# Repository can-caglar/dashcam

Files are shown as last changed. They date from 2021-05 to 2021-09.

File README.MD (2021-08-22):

# DASHCAM PROJECT

This is the development repo for a low-cost, dash-cam hobby project.

**Features:**

1. Small size (34 x 34 x 34 cm)

2. Saves videos to AVI format (motion JPEG).

3. Powered through a USB mini cable.

4. Can connect to WiFi. The idea is to connect it to your phone hotspot, after which the video will be streamed to a local server that the driver can access on their phone's internet browser. This is to help the driver position the camera by seeing what the camera is seing.

5. Small OLED screen and 3 buttons for the UI. OLED will show the device IP address for the video streaming server, and show nearby WiFi access points.

6. Inexpensive looking (due to very small design). Will not encourage thieves!

7. Has a supercapacitor which keeps power active for ~ 1 second after power is cut, this means videos will never be corrupt.

8. SD card slot which overrides oldest videos, so the device will never run out of memory. 

9. It's a cube! The x, y and z dimentions have been distributed equally so it takes up as little space from the driver's perspective as possible.

## Latest update:

**Proven concepts**

- Videos can be saved on an ESP32 using an AVI format.

- Supercapacitor keeps the device on long enough for the video to save after abrupt power down.

- OLED library allows scrolling text, so long messages, i.e. IP address of device can be shown easily. 

**Hardware**

PCB spin 1 has arrived and components have been soldered.

The ESP32 can be programmed and can run a basic "hello world" script without issues.

Full circuit could not be tested because the 0.5 mm pitch FPC connectors proved difficult to solder without a hot air gun.

More details can be found in [Project_planning.xlsx](https://github.com/jhancharler/dashcam/blob/master/project_plan/Project_planning.xlsx "Project_planning.xlsx").

## Images:

**Top-side images:**
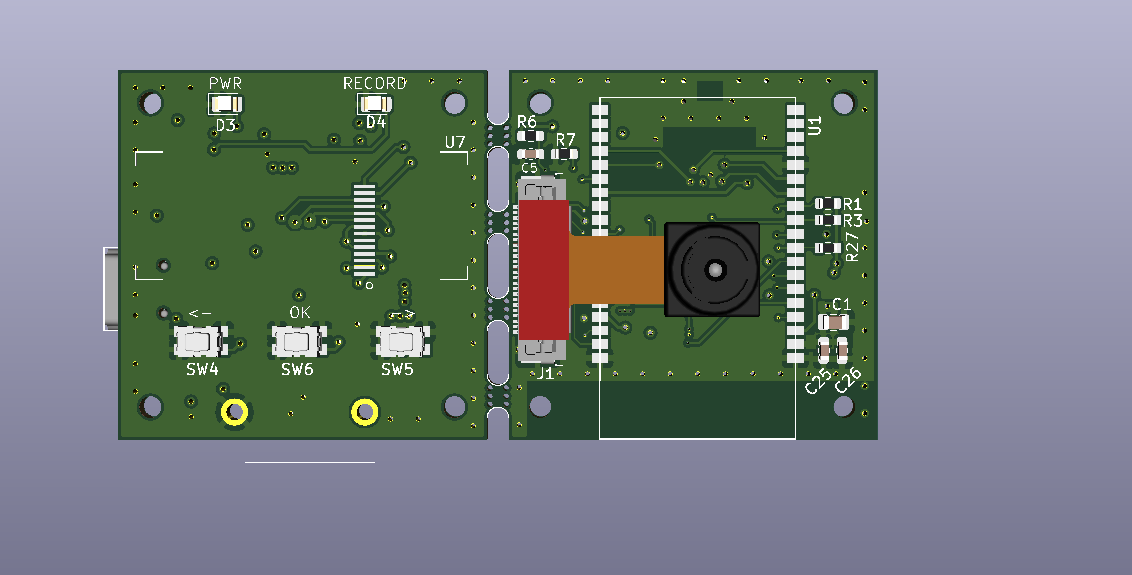
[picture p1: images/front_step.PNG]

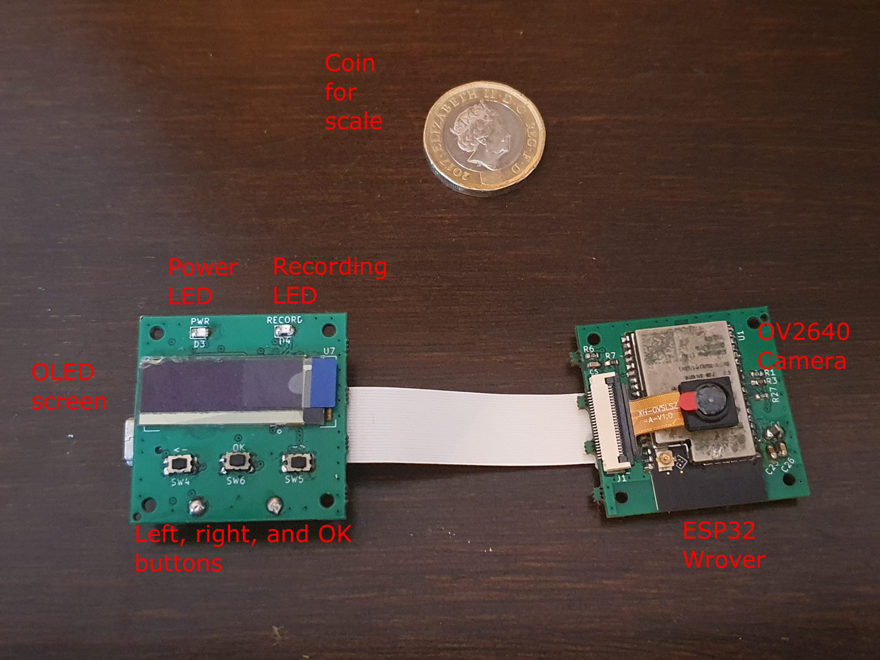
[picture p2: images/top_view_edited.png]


**Back images:**
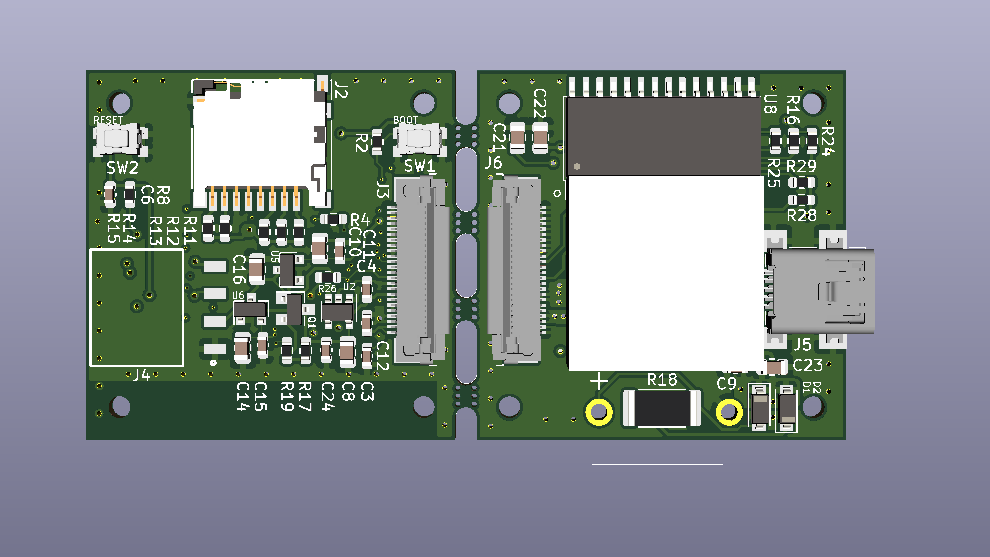
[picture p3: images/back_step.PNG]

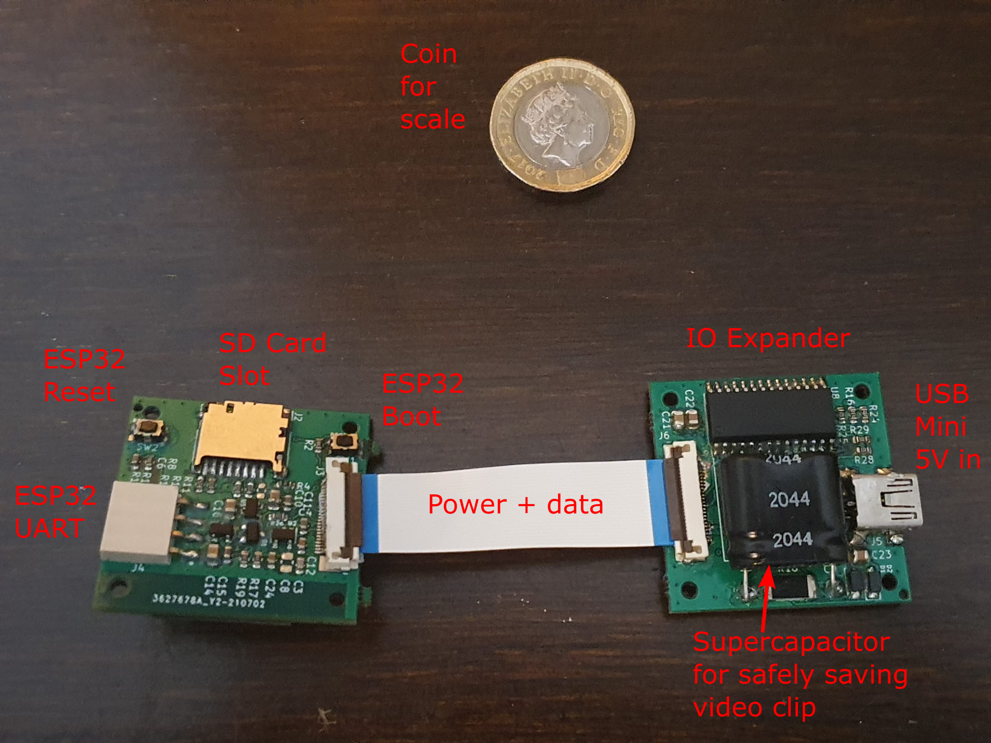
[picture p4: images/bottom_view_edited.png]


**Upright images:**
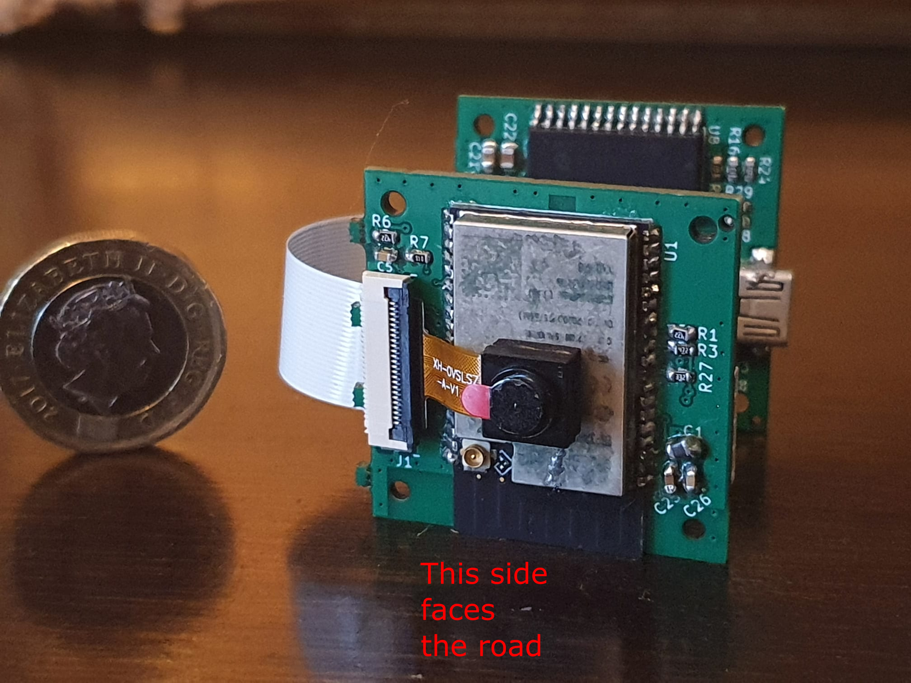
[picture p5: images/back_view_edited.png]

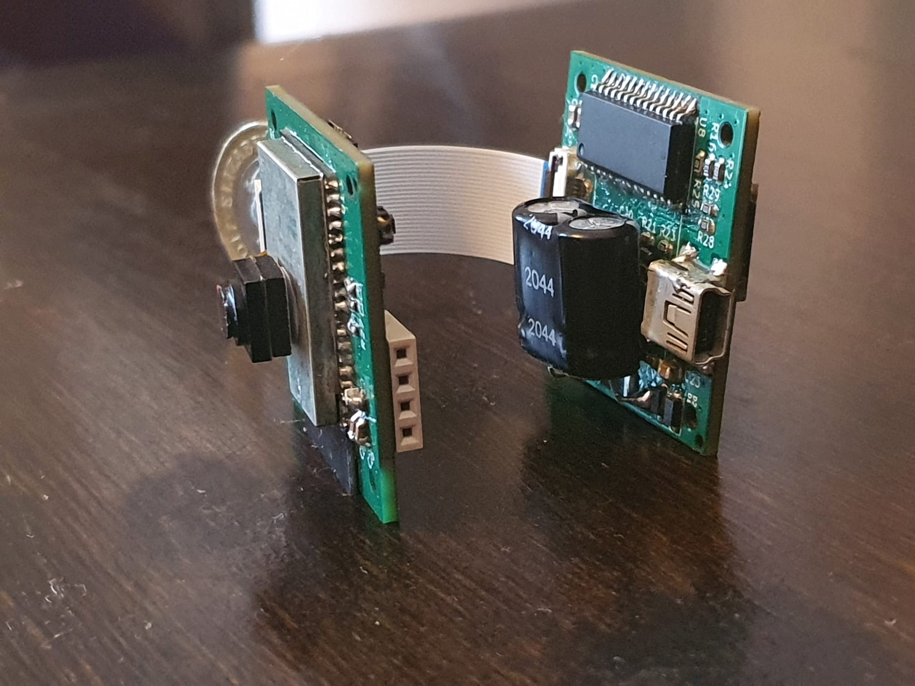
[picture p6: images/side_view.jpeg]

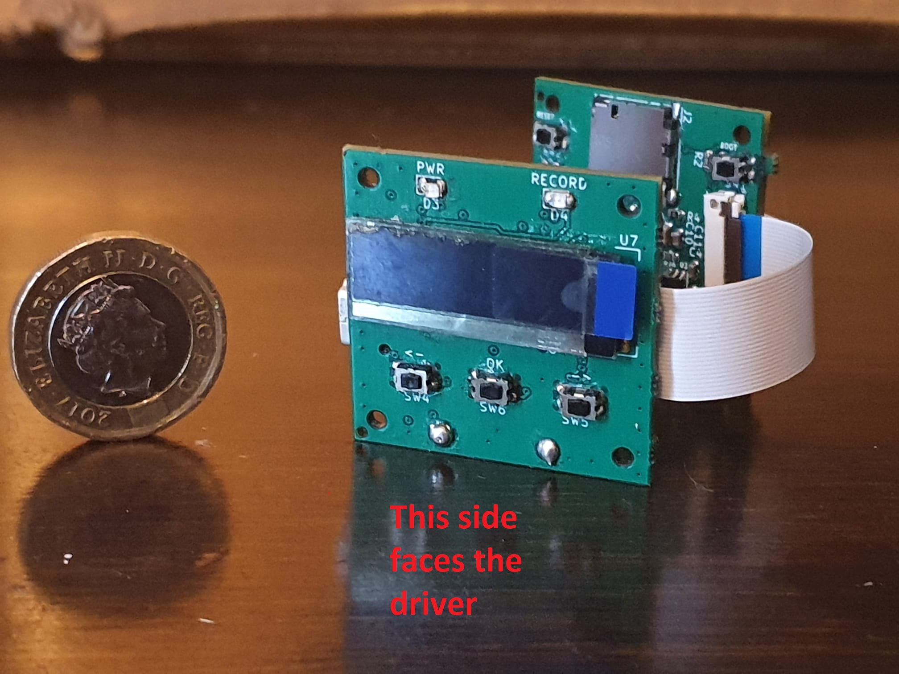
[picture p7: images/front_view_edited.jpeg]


**In-car concept:**

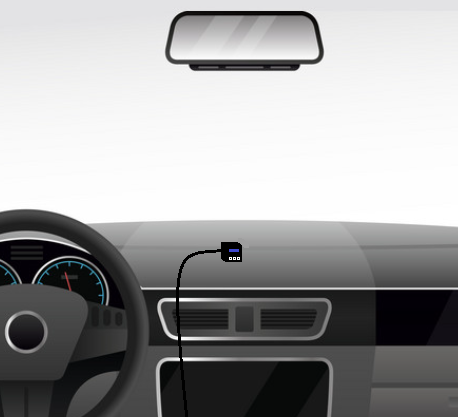
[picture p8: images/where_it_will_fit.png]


**PCB view** 
*KiCAD files for the project can be found [here](https://github.com/jhancharler/dashcam/tree/master/hardware/schem_1)):
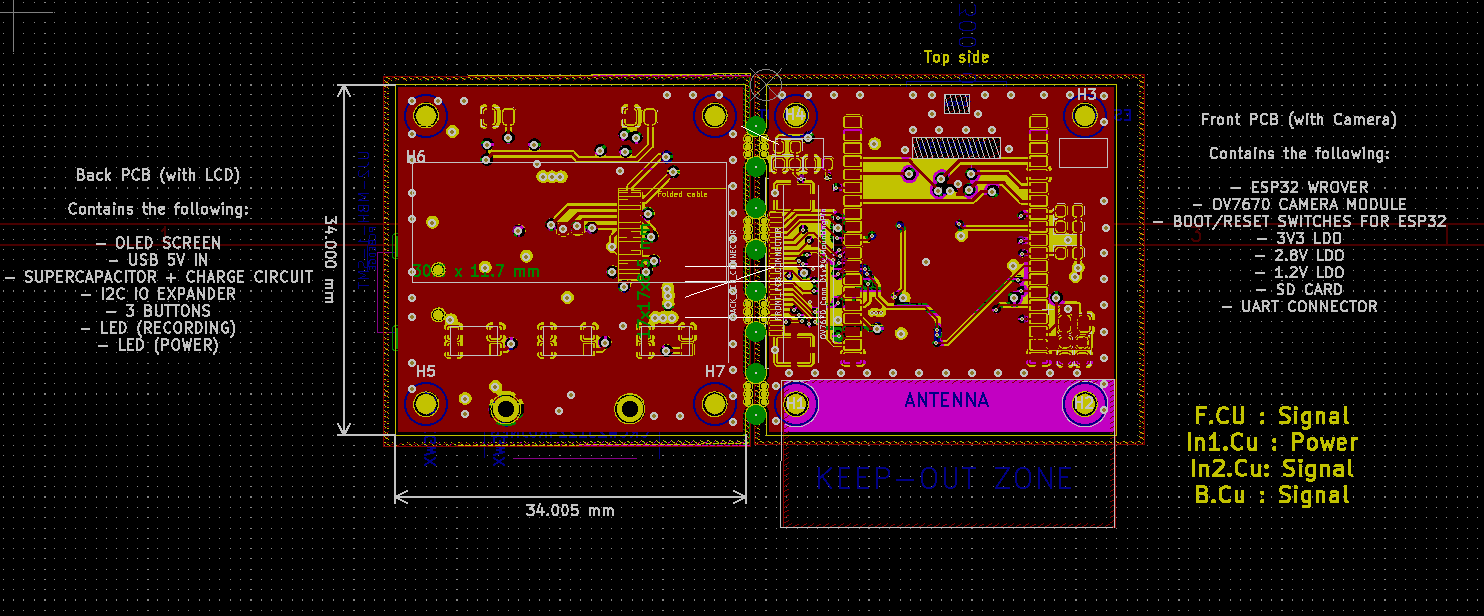
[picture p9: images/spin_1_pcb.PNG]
*

## Progress log

To see the progress log and design decisions, go to the /project_plan folder to see the various plan documents.

## Installation

Will be added once firmware is written for device.

```bash
```

## Usage

Will be added once firmware is written for device.

```python
```

## License
[MIT](https://choosealicense.com/licenses/mit/)

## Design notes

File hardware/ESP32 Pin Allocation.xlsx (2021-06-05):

Wroom32 | Name | Input | Output | ADC | PWM | DAC | UART | SPI | I2C | Strap | HAB | ESP32-CAM |  | Notes | Additional notes
25 | GPIO0 | Pulled up | OK | ADC2_CH1 |  |  |  |  |  | Y |  | CSI_MCLK |  | Outputs PWM signal at boot
35 | GPIO1 | x | OK |  |  |  | TX |  |  |  | Y | U0TXD |  | Outputs debug info at boot
24 | GPIO2 | OK | OK | ADC2_CH2 | Y |  |  |  |  | Y |  | HS2_DATA0 |  | Connected to Wroom32 onboard LED
34 | GPIO3 | OK | x |  |  |  | RX |  |  |  | Y | U0RXD + OLED SCL |  | HIGH at boot | SCL
26 | GPIO4 | OK | OK | ADC2_CH0 | Y |  |  |  |  | Y |  | HS2_DATA1
29 | GPIO5 | OK | OK |  | Y |  |  | SS |  | Y | Y | CSI_D0 |  | Could make use of this (disconnect from camera: image quality may not be affected much) | Reducing to 7 bit video means 128 bits per channel, so 128*128*128 = roughly 2 million colours. Human eye can perceive around 10 million colours, so users can tell the difference.
14 | GPIO12 | OK | OK | ADC2_CH5 | Y |  |  |  |  | Y |  | HS2_DATA2 |  | Boot fail if pulled high
16 | GPIO13 | OK | OK | ADC2_CH4 | Y |  |  |  |  |  |  | HS2_DATA3 |  |  | I2C pins pulled high at boot. They are fine here
13 | GPIO14 | OK | OK | ADC2_CH6 | Y |  |  |  |  |  | Y | HS2_CLK |  | Outputs PWM signal at boot | I2C pins pulled high at boot. They are fine here
23 | GPIO15 | OK | OK | ADC2_CH3 | Y |  |  |  |  | Y | Y | HS2_CMD |  | Outputs PWM signal at boot
27 | GPIO16 | OK | OK |  | Y |  | RX2 |  |  |  |  | PSRAM_CS |  | Could make use of this if low res image ok
28 | GPIO17 | OK | OK |  | Y |  | TX2 |  |  |  |  | PSRAM_CLK |  | Could make use of this if low res image ok
30 | GPIO18 | OK | OK |  | Y |  |  | SCK |  |  |  | CSI_D1
31 | GPIO19 | OK | OK |  | Y |  | CTS | CIPO |  |  |  | CSI_D2
33 | GPIO21 | OK | OK |  | Y |  |  |  | SDA |  |  | CSI_D3
36 | GPIO22 | OK | OK |  | Y |  | RTS |  | SCL |  |  | CSI_PCLK
37 | GPIO23 | OK | OK |  | Y |  |  | COPI |  |  |  | CSI_HSYNC
10 | GPIO25 | OK | OK | ADC2_CH8 | Y | DAC1 |  |  |  |  |  | CSI_VSYNC
11 | GPIO26 | OK | OK | ADC2_CH9 | Y | DAC2 |  |  |  |  |  | TWI_SDA
12 | GPIO27 | OK | OK | ADC2_CH7 | Y |  |  |  |  |  |  | TWI_SCK
8 | GPIO32 | OK | OK | ADC1_CH4 | Y |  |  |  |  |  |  | CAM_PWR
9 | GPIO33 | OK | OK | ADC1_CH5 | Y |  |  |  |  |  |  | OLED SDA |  | OLED addr = 0x3C | IO expander address [7:0] = 0 1 0 0 A2 A1 A0
w | GPIO34 | OK | x | ADC1_CH6 |  |  |  |  |  |  |  | CSI_D6 |  | Input only. No pullup / pulldown.
7 | GPIO35 | OK | x | ADC1_CH7 |  |  |  |  |  |  |  | CSI_D7 |  | Input only. No pullup / pulldown.
4 | GPIO36 | OK | x | ADC1_CH0 |  |  |  |  |  |  |  | CSI_D4 |  | Input only. No pullup / pulldown. | GPIO36 (SENSOR_VP)
5 | GPIO39 | OK | x | ADC1_CH3 |  |  |  |  |  |  |  | CSI_D5 |  | Input only. No pullup / pulldown. | GPIO39 (SENSOR_VN)
 |  |  |  | ADC2 doesn't work when WiFi is in use |  |  |  |  |  |  |  |  | Dash-cam peripherals
 |  |  |  |  |  |  |  |  |  |  |  |  | Note: SD card can't share SPI bus since it needs to keep CS asserted throughout entire xfer. Reference: https://github.com/espressif/esp-idf/issues/1597#issuecomment-365364458
 |  |  |  |  |  |  |  |  |  |  |  |  | Note2: Perhaps it can…see https://github.com/espressif/esp-idf/issues/1597#issuecomment-585853701
Spreadsheet template found at: https://www.superhouse.tv/esp32-pin-allocation-spreadsheet/

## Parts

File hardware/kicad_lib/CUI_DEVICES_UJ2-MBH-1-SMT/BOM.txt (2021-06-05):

3DX_CUI_DEVICES_Supplier: CUI Devices
3DX_CUI_DEVICES_Description: 3 µin Plating Thickness, Black Insulator, USB Receptacle
3DX_CUI_DEVICES_Model Number: UJ2-MBH-1-SMT

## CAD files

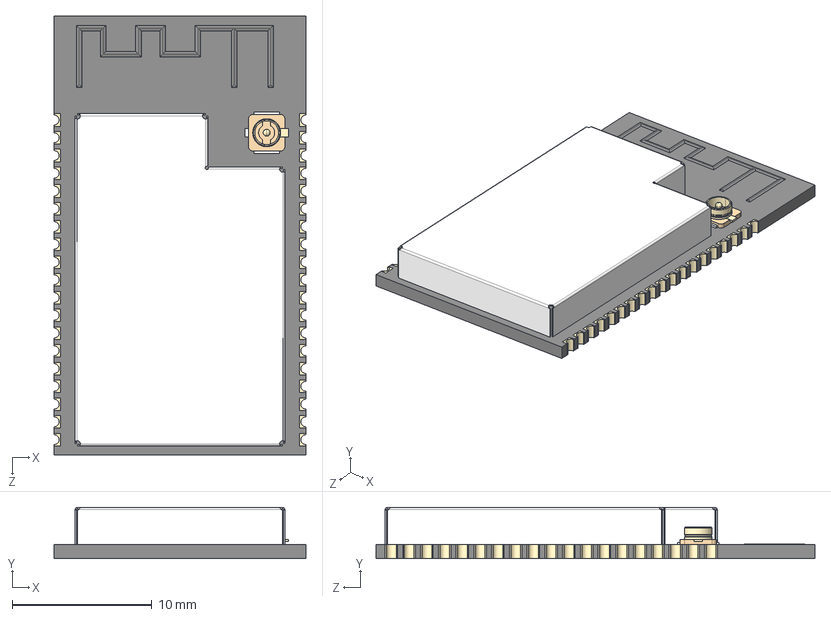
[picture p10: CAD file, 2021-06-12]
hardware/3d_models/components/ESP32-WROVER-I--3DModel-STEP-56544.STEP
18.0 x 3.65 x 31.4 mm

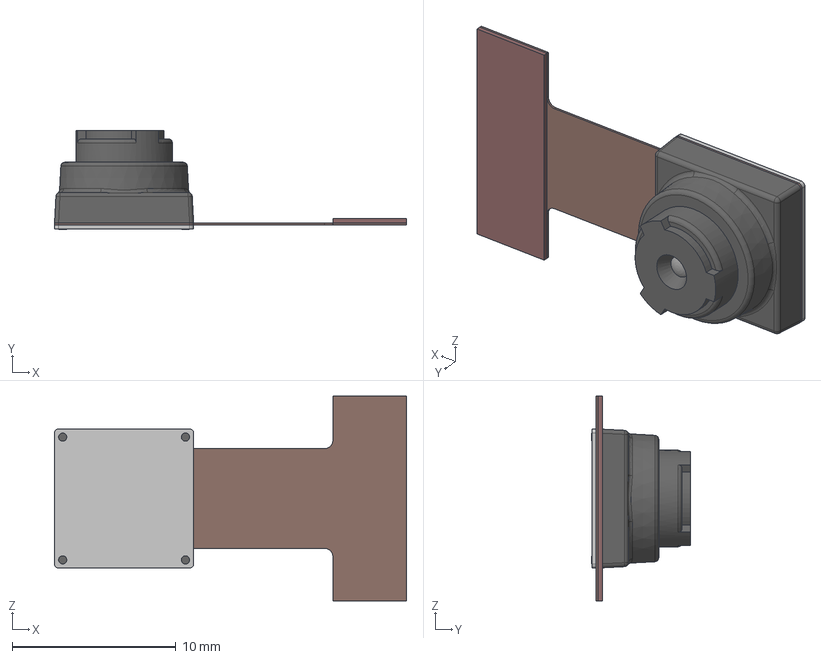
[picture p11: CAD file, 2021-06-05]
hardware/3d_models/components/OV7670/OV7670.FCStd
21.5 x 6.03 x 12.5 mm
User Library-ov9655_ov9655_flex_pcb
User Library-ov9655_ov9655_flex_reinf
User Library-ov9655_ov9655_back_panel
User Library-ov9655_ov9655_body
User Library-ov9655_ov9655_lens

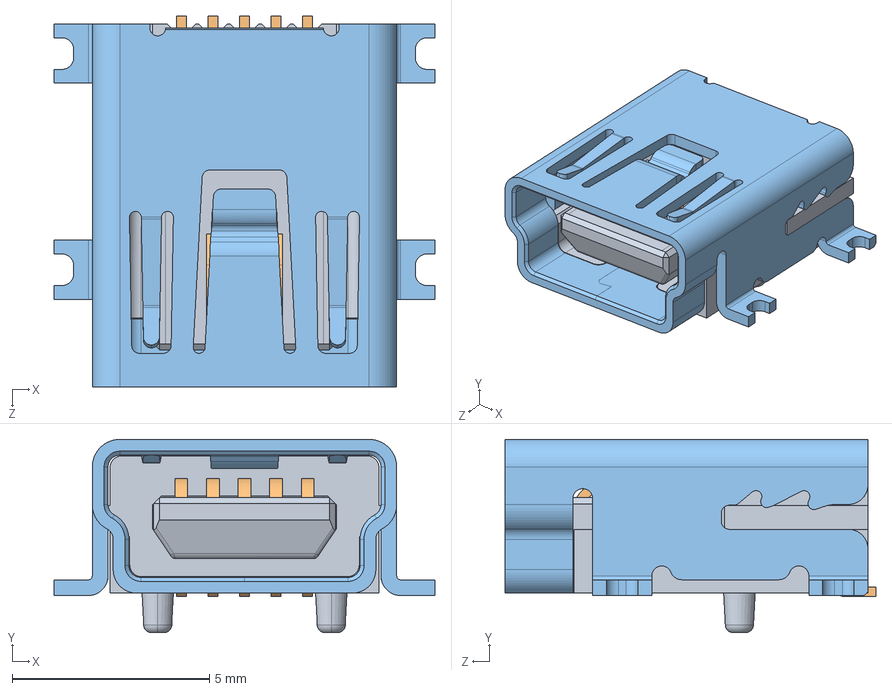
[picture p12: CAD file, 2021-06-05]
hardware/kicad_lib/CUI_DEVICES_UJ2-MBH-1-SMT/CUI_DEVICES_UJ2-MBH-1-SMT.step
9.66 x 4.90 x 9.40 mm
internal housing
5_1_Pin x 5
housing

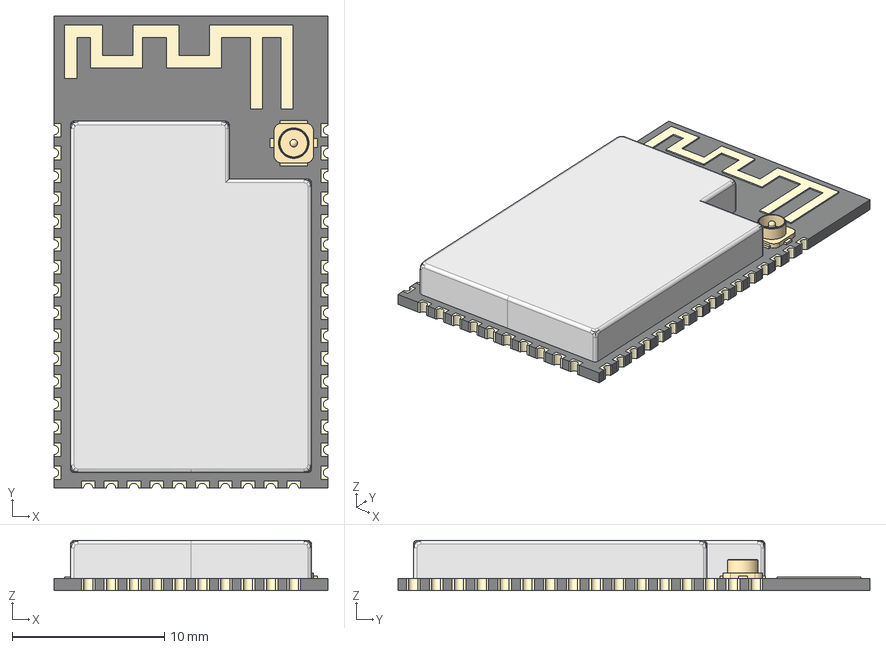
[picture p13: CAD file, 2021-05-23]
hardware/kicad_lib/ESP32-S2-WROVER/ESP32-S2-WROVER.step
18.0 x 31.0 x 3.30 mm
PCB
Castellations
Trace Antenna
UFL Connector
Can

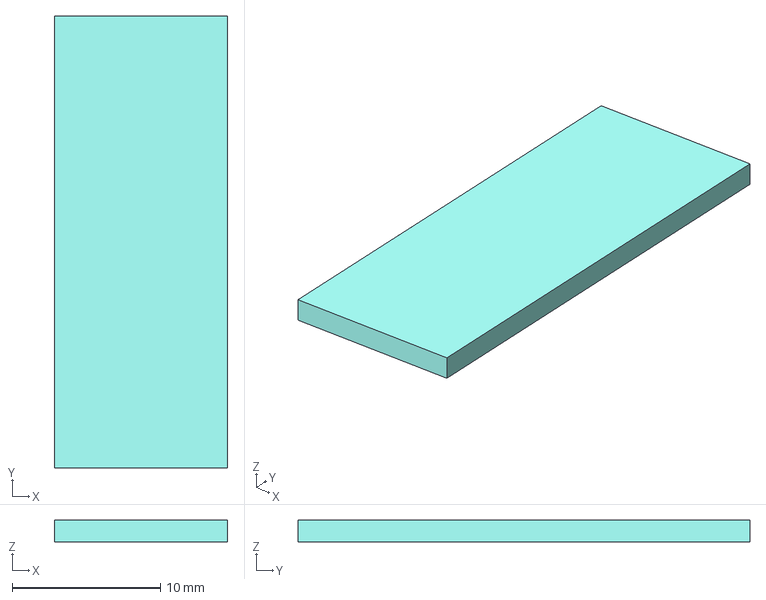
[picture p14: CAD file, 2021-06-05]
hardware/3d_models/components/OLED_screen-Body.step
11.7 x 30.5 x 1.46 mm

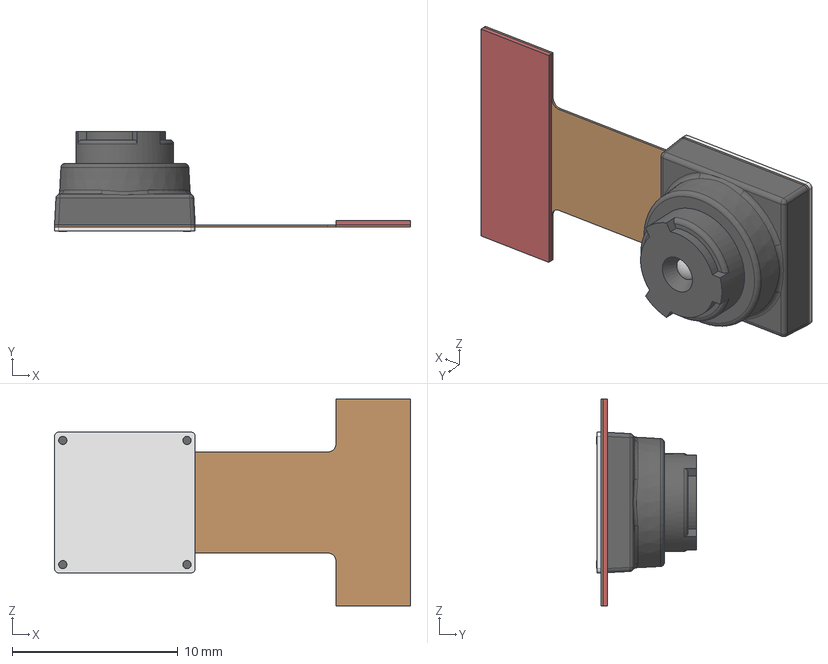
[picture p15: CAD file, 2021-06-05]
hardware/3d_models/components/OV7670/OV7670-OV7670.step
21.5 x 6.03 x 12.5 mm
User Library-ov9655_ov9655_flex_pcb
User Library-ov9655_ov9655_flex_reinf
User Library-ov9655_ov9655_back_panel
User Library-ov9655_ov9655_body
User Library-ov9655_ov9655_lens

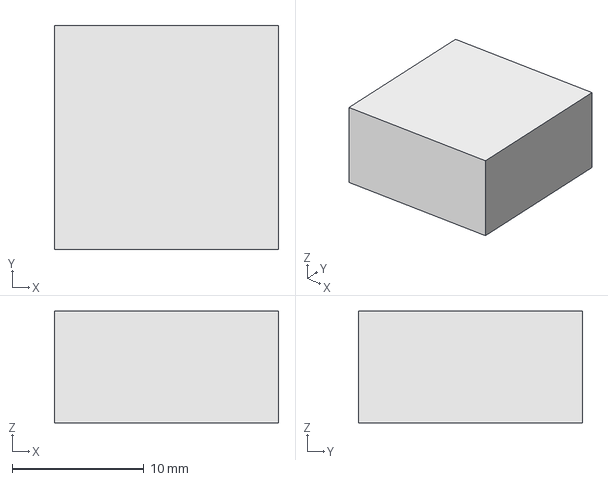
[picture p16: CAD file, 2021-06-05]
hardware/3d_models/components/DGH105Q5R5.FCStd
17.0 x 17.0 x 8.50 mm

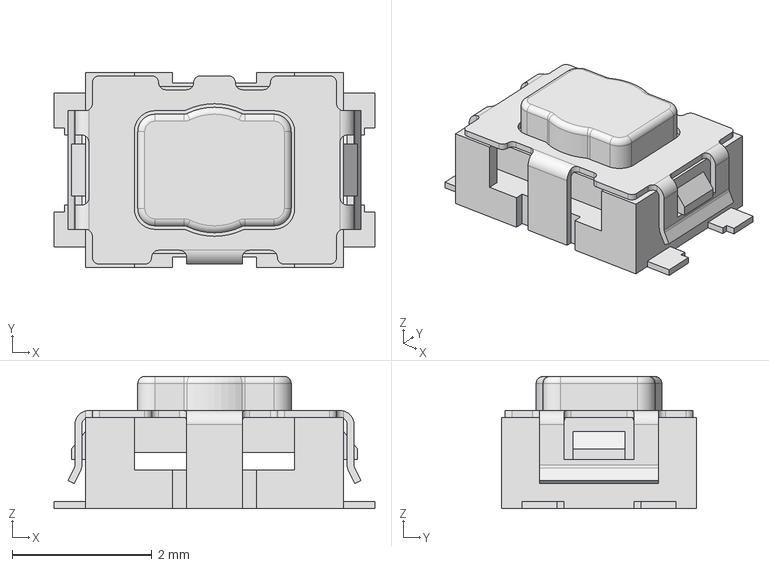
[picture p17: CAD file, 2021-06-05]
hardware/3d_models/components/TL6330AF200Q.stp
4.60 x 2.80 x 1.90 mm

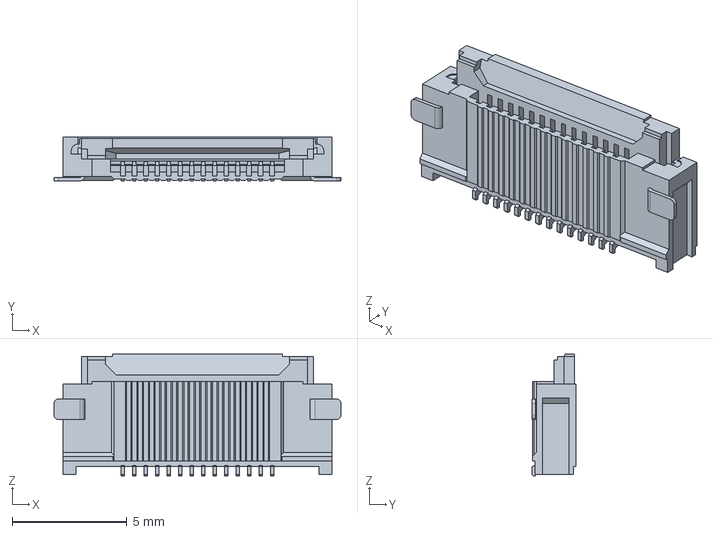
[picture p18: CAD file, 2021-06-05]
hardware/3d_models/components/molex_ffc_connector_5051101492.stp
12.5 x 1.90 x 5.30 mm

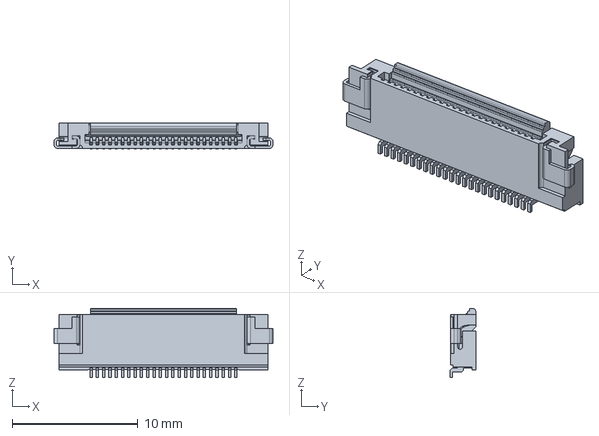
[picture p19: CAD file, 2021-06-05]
hardware/3d_models/components/52892-2433_stp/528922433.stp
17.4 x 2.04 x 5.50 mm

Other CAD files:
hardware/3d_models/components/OLED_screen.FCStd

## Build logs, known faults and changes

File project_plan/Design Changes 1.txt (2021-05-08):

-------------------- Design Changes 1  (03/05/2021) ----------------

After reasearching Bluetooth and Flutter, it was decided that these
two items add too much risk to the project. The reason is due to a lack of experience designing bluetooth and mobile applications.

Since this is purely software based, these features can be added at a later date with a software update.

Although a bluetooth phone app would be a very neat feature on the product (push button on app, download
image from ESP32- minimal set up) it adds far too much risk of increasing time of development.

So how to display camera view to user?

1. I plan to keep this feature as I think it's important to see the camera view.

2. Although it would be easier to implement, I plan to avoid a large LCD to display the image as this 
will be too expensive, make the item more attractive to thieves and drain the battery too much.

3. Settled on an alternative:

- Host a HTTP/HTTPS server on the ESP32 which sends camera buffer when requested.

- Use SD card to configure WiFi credentials beforehand in a text file.

- User will enable mobile tethering so the esp32 can join its network.

- Install an OLED display to show ESP32's ip address. Note: keeping OLED as small as possible for reasons 
mentioned in point 2.) The 128x32 displays using SSD1306 controller from BuyDisplay seem like an excellent 
choice (~£2 each).

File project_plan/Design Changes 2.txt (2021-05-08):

-------------------- Design Changes 2  (08/05/2021) ----------------

The device will no longer have a back-up battery supply. The power will be provided entirely by USB.

To prevent video corruption at power loss, a supercapacitor will be added to keep the device awake until it can perform a safe switch off.

The reason for these changes are as follows:

1. Most dashcams on the market require being plugged in to power for use. Their batteries do not last long. So customers are used to 
plugging their dash-cams to power anyway.
2. NiMH batteries do not do well in high temperatures, and it is too risky to have them in a car i.e. in the summer, without doing extensive 
testing which would delay the project completion too much.
3. Li-Ion batteries can handle high temperatures, but they are too risky to charge and may cause concern for customers.
4. Battery placement and size was causing issues. I.e. where to put them; front has camera, back has OLED.

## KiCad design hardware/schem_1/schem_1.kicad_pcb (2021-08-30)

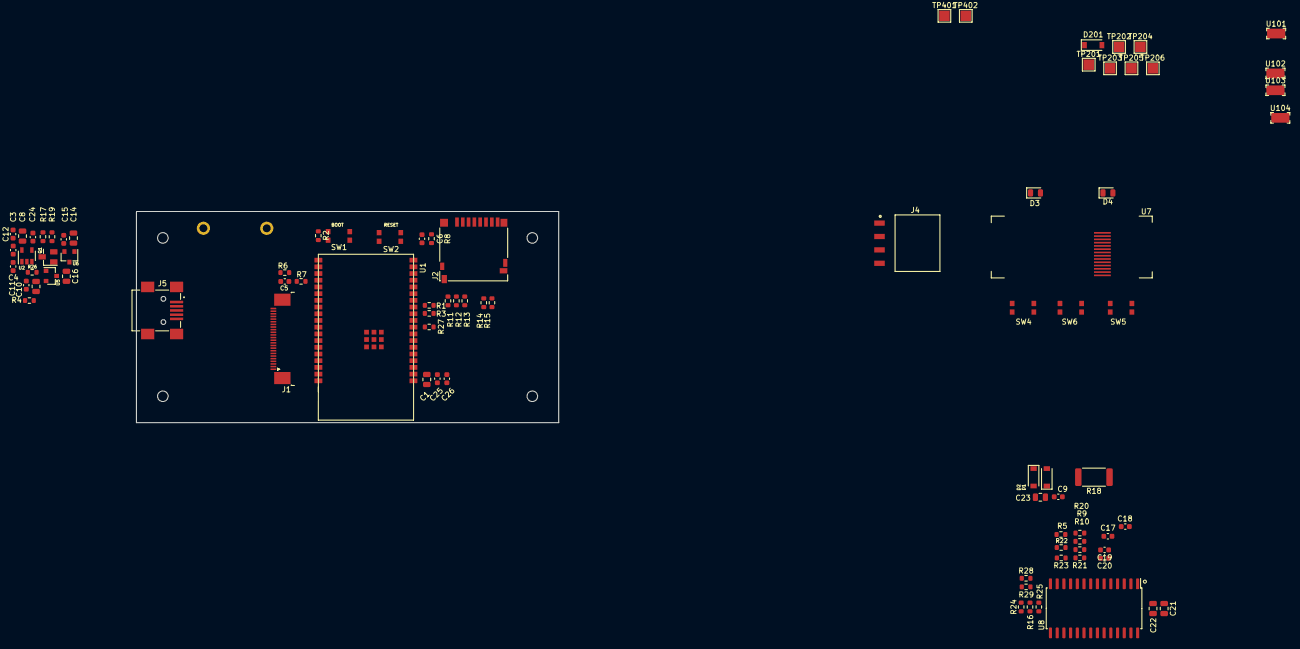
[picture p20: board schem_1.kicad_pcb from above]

Board: 4 copper layers, 80.0 x 40.0 mm, 90 parts (1 on the bottom side), 56 nets, no tracks yet.

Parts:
C1: 47uF/6.3V/20%/0805; C_0805_2012Metric
C2: DGH105Q5R5; DGH105Q5R5-Horizontal
C3: 15pF; C_0603_1608Metric
C4, C5, C11, C15, C26: 0.1uF; C_0603_1608Metric
C6, C9, C12, C17, C18, C19, C20, C24, C25: 1uF; C_0603_1608Metric
C8: 10uF DNF; C_0805_2012Metric
C10, C14, C16, C21, C22, C23: 10uF; C_0805_2012Metric
D1, D2, D201: PMEG2005EGWX; D_SOD-123
D3: LED_GREEN; LED_0805_2012Metric
D4: LED; LED_0805_2012Metric
H1, H2, H3, H4: MountingHole; MountingHole_2mm
J1: OV7670_Conn_01x24_MountingPin; TE_2-1734839-4_1x24-1MP_P0.5mm_Horizontal
J2: Micro_SD_Card; microSD_HC_Hirose_DM3D-SF
J4: BG300-04-X-X-A_REVC; GCT_BG300-04-X-X-A_REVC
J5: UJ2-MBH-1-SMT; CUI_UJ2-MBH-1-SMT
Q1: NDS332P; SuperSOT-3
R1, R3, R6: 4.7K; R_0603_1608Metric
R2, R17, R20: 10k; R_0603_1608Metric
R4, R5: 0R; R_0603_1608Metric
R7: 1K; R_0603_1608Metric
R8: 10K; R_0603_1608Metric
R9, R10, R26, R27, R28, R29: 3.3k; R_0603_1608Metric
R11: DNC; R_0603_1608Metric
R12, R13, R14, R15: 47K; R_0603_1608Metric
R16, R25: 470; R_0603_1608Metric
R18: CRCW251224R0JNEG; R_2512_6332Metric
R19: 1k; R_0603_1608Metric
R21: 300k; R_0603_1608Metric
R22: 100k; R_0603_1608Metric
R23: 150k; R_0603_1608Metric
R24: 2k2; R_0603_1608Metric
SW1: BTN_BOOT; JC_Switch_TL6330
SW2: ESP32_RESET; JC_Switch_TL6330
SW4: DOWN; JC_Switch_TL6330
SW5: UP; JC_Switch_TL6330
SW6: OK; JC_Switch_TL6330
TP201, TP202, TP203, TP204, TP205, TP206, TP401, TP402: TestPoint; TestPoint_Pad_2.0x2.0mm
U1: ESP32-WROVER-E-JC
U2: XC6210B332MR; SOT-23-5
U5: XC6206-2.8V; SOT-23
U6: XC6206-1.2V; SOT-23
U7: 128x32_OLED_SSD1306; ER-OLED0.91-7W_SSD1306
U8: MCP23017_SO; SOIC-28W_7.5x17.9mm_P1.27mm
U101, U102, U103, U104: 0805_TEST_POINT; PC_TEST_POINT_SMD

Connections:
+1V2: C14.1, C15.1, J1.15, TP206.1, U6.2
+2V8: C10.1, C11.1, J1.21, TP205.1, U5.2
+3V3: C1.1, C4.2, C8.1, C19.1, C20.1, C24.1, C25.1, C26.1, J1.14, J2.4, Q1.3, R1.2, R2.1, R3.2, R6.2, R8.1, R9.1, R10.1, R11.1, R12.1, R13.1, R14.1, R15.1, R16.1, R17.1, R20.1, R24.1, R26.2, R27.1, R28.1, R29.1, TP203.1, U1.2, U2.5, U7.5, U7.8, U8.9
/5V_USB_SC: C9.1, C23.1, D2.2, D201.2, J4.4, J5.1, R22.1, TP201.1
/CAM_PWR: R19.2, TP204.1, U1.8
/CAM_RST: C5.1, J1.19, R6.1
/CSI_D0: R4.2, U1.29
/CSI_D1: J1.4, U1.30
/CSI_D2: J1.3, U1.31
/CSI_D3: J1.5, U1.33
/CSI_D4: J1.7, U1.4
/CSI_D5: J1.9, U1.5
/CSI_D6: J1.11, U1.6
/CSI_D7: J1.13, U1.7
/CSI_HSYNC: J1.16, U1.37
/CSI_MCLK: J1.12, R2.2, SW1.1, U1.25
/CSI_PCLK: C3.2, J1.8, U1.36
/CSI_VSYNC: J1.18, U1.10
/ESP32_RST: C6.1, R8.2, SW2.1, U1.3
/GPIO Expander/BTN_DOWN: SW4.1, U8.26
/GPIO Expander/BTN_OK: SW6.1, U8.28
/GPIO Expander/BTN_UP: SW5.1, U8.27
/GPIO Expander/LED_RECORDING: R25.1, U8.24
/GPIO Expander/Vusb_detect: R22.2, R23.1, TP401.1, U8.25
/HS2_CLK: J2.5, U1.13
/HS2_CMD: J2.3, R13.2, U1.23
/HS2_DATA0: J2.7, R14.2, U1.24
/HS2_DATA1: J2.8, R15.2, U1.26
/HS2_DATA2: J2.1, R11.2, U1.14
/HS2_DATA3: J2.2, R12.2, U1.16
/I2C OLED/OLED_RESET: R20.2, U7.9
/SCL: J4.2, R9.2, R26.1, R29.2, U1.34, U7.10, U8.12, U103.1
/SDA: R10.2, R27.2, R28.2, U1.9, U7.11, U8.13, U101.1
/TWI_SCK: J1.20, R1.1, U1.12
/TWI_SDA: J1.22, R3.1, U1.11
/U0TXD: J4.3, U1.35, U102.1
GND: C1.2, C3.1, C4.1, C5.2, C6.2, C8.2, C9.2, C10.2, C11.2, C12.2, C14.2, C15.2, C16.2, C19.2, C20.2, C21.2, C22.2, C23.2, C24.2, C25.2, C26.2, D3.1, D4.1, J1.10, J1.23, J1.MP, J2.6, J2.9, J4.1, J5.5, J5.SH1, J5.SH2, J5.SH3, J5.SH4, R7.1, R21.2, R23.2, SW1.2, SW2.2, SW4.2, SW5.2, SW6.2, U1.1, U1.15, U1.38, U1.39, U2.2, U5.1, U6.1, U7.7, U8.10, U8.15, U8.16, U8.17, U104.1
unnamed: C12.1, D1.1, D201.1, TP202.1, U2.1, U2.3
unnamed: C16.1, Q1.1, U5.3, U6.3
unnamed: C17.1, U7.1
unnamed: C17.2, U7.2
unnamed: C18.1, U7.3
unnamed: C18.2, U7.4
unnamed: C21.1, U7.13
unnamed: C22.1, U7.14
unnamed: D1.2, R18.2
unnamed: D2.1, R18.1
unnamed: D3.2, R16.2
unnamed: D4.2, R25.2
unnamed: J1.6, R4.1
unnamed: J1.17, R7.2
unnamed: J5.2, R5.1
unnamed: J5.3, R5.2
unnamed: Q1.2, R17.2, R19.1
unnamed: R21.1, U7.12
unnamed: R24.2, TP402.1, U8.18

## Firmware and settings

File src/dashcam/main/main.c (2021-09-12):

/* Hello World Example
   This example code is in the Public Domain (or CC0 licensed, at your option.)
   Unless required by applicable law or agreed to in writing, this
   software is distributed on an "AS IS" BASIS, WITHOUT WARRANTIES OR
   CONDITIONS OF ANY KIND, either express or implied.
*/
#include <stdio.h>
#include "sdkconfig.h"
#include "freertos/FreeRTOS.h"
#include "freertos/task.h"
#include "esp_system.h"
#include "esp_spi_flash.h"
#include "esp_log.h"
#include "driver/i2c.h"
#include "esp_err.h"
#include "memory.h"

#define SDA GPIO_NUM_3
#define SCL GPIO_NUM_16 
#define I2C_MAX_CLOCK_SPEED 400000
#define I2C_MASTER_TIMEOUT_MS 1000

#define IOEXPANDER_ADDR 0x20

#define OPCODE_AND_RW(slave_addr, rw) ((slave_addr << 1) | (rw))
#define READ_BIT(buffer, bit) ((buffer) >> (bit) & 1)

#define I2C_PORT I2C_NUM_0

#define ACK_EN 1
#define NACK   0

const char* TAG = "DASHCAM_MAIN";

// Below is the IOCON.BANK = 0 addressing
#define IODIRA      0x00
#define IODIRB      0x01
#define IPOLA       0x02
#define IPOLB       0x03
#define GPINTENA    0x04
#define GPINTENB    0x05
#define DEFVALA     0x06
#define DEFVALB     0x07
#define INTCONA    0x08
#define INTCONB     0x09
#define IOCONA      0x0A
#define IOCONB      0x0B
#define GPPUA       0x0C
#define GPPUB       0x0D
#define INTFA       0x0E
#define INTFB       0x0F
#define INTCAPA     0x10
#define INTCAPB     0x11
#define GPIOA       0x12
#define GPIOB       0x13
#define OLATA       0x14
#define OLATB       0x15

#define IO_EXPANDER_INPUT  1
#define IO_EXPANDER_OUTPUT 0

#define OK_BUTTON 7
#define DOWN_BUTTON 6
#define BLUE_LED 5
#define USB_DETECT 4

// IOCON bits
#define IOCON_INTPOL (1 << 1)
#define IOCON_ODR    (1 << 2)


enum gpio_bank
{
    PORT_A = 0,
    PORT_B = 1
};

enum io_direction
{
    DIR_OUTPUT = 0,
    DIR_INPUT = 1
};

enum pull_up_state
{
  PULLUP_DISABLED = 0,
  PULLUP_ENABLED = 1,
  PULLUP_NOT_APPLICABLE = 2,
};

enum interrupt_trigger
{
    MCP_RISING = 0,
    MCP_FALLING = 1,
    MCP_ANY = 2,
};

// Prototypes
esp_err_t init_gpio(enum gpio_bank bank, const uint8_t gpio_number, enum io_direction dir, enum pull_up_state pullup_en);
esp_err_t configure_interrupt(enum gpio_bank bank, uint8_t gpio_number, enum interrupt_trigger int_trigger);

esp_err_t i2c_write_slave_register(uint8_t addr, uint8_t data)
{
    i2c_cmd_handle_t cmd;
    esp_err_t err = ESP_OK;

    // TODO: ERROR CHECKING for input params

    ESP_LOGI(TAG, "Writing [0x%2x] to register %2x", data, addr);

     // 1. CMD link  
    cmd = i2c_cmd_link_create();

    // 2. Start bit
    err = i2c_master_start(cmd);
    if (err) goto exit;

    //3. OP (opcode + read/write) - requires an ACK
    err = i2c_master_write_byte(cmd, OPCODE_AND_RW(IOEXPANDER_ADDR, I2C_MASTER_WRITE), ACK_EN);
    if (err) goto exit;

    //4. Write register address - requires an ACK
    err = i2c_master_write_byte(cmd, addr, ACK_EN);
    if (err) goto exit;

    //5. SR condition (start stop / restart)
    err = i2c_master_start(cmd);
    if (err) goto exit;

    //6. OP (opcode + write) - requires an ACK
    err = i2c_master_write_byte(cmd, OPCODE_AND_RW(IOEXPANDER_ADDR, I2C_MASTER_WRITE), ACK_EN);
    if (err) goto exit;

    //7. Write 1 byte to slave register
    err = i2c_master_write_byte(cmd, data, NACK);
    if (err) goto exit;

    //6. Stop bit
    err = i2c_master_stop(cmd);
    if (err) goto exit;

    //7. Execute command
    err = i2c_master_cmd_begin(I2C_PORT, cmd, pdMS_TO_TICKS(I2C_MASTER_TIMEOUT_MS));

    ESP_LOGI(TAG, "Finished writing data [0x%02x] to address %02x", data, addr);

exit:

    i2c_cmd_link_delete(cmd);

    if (err) ESP_LOGE(TAG, "%s", esp_err_to_name(err));

    return err;
}

esp_err_t i2c_read_slave_register(uint8_t addr, uint8_t* rx_buf)
{
    i2c_cmd_handle_t cmd;
    esp_err_t err = ESP_OK;
    *rx_buf = 0x00;

    // TODO: ERROR CHECKING for input params

    ESP_LOGI(TAG, "Reading address 0x%2x", addr);

     // 1. CMD link  
    cmd = i2c_cmd_link_create();

    // 2. Start bit
    err = i2c_master_start(cmd);
    if (err) goto exit;

    //3. OP (opcode + read/write) - requires an ACK
    err = i2c_master_write_byte(cmd, OPCODE_AND_RW(IOEXPANDER_ADDR, I2C_MASTER_WRITE), ACK_EN);
    if (err) goto exit;

    //4. Write register address - requires an ACK
    err = i2c_master_write_byte(cmd, addr, ACK_EN);
    if (err) goto exit;

    //5. SR condition (start stop / restart)
    err = i2c_master_start(cmd);
    if (err) goto exit;

    //6. OP (opcode + read/write) - requires an ACK
    err = i2c_master_write_byte(cmd, OPCODE_AND_RW (IOEXPANDER_ADDR, I2C_MASTER_READ), ACK_EN);
    if (err) goto exit;

    //7. Read x bytes from slave
    err = i2c_master_read(cmd, rx_buf, sizeof(uint8_t), ACK_EN);
    if (err) goto exit;

    //6. Stop bit
    err = i2c_master_stop(cmd);
    if (err) goto exit;

    //7. Execute command
    err = i2c_master_cmd_begin(I2C_PORT, cmd, pdMS_TO_TICKS(I2C_MASTER_TIMEOUT_MS));

    ESP_LOGI(TAG, "Register 0x%02x = [0x%02x]", addr, rx_buf[0]);

exit:

    i2c_cmd_link_delete(cmd);

    if (err) ESP_LOGE(TAG, "%s", esp_err_to_name(err));

    return err;
}

esp_err_t init_mcp23017()
{
    // Note, IOCON.BANK should be 0 during boot, so we know how the registers 
    // will be addressed

    esp_err_t err = ESP_OK;

    // GPIO A7 is BUTTON OK (input)
    init_gpio(PORT_A, OK_BUTTON, DIR_INPUT, PULLUP_ENABLED);
    configure_interrupt(PORT_A, OK_BUTTON, MCP_ANY);

    // GPIO A6 is BUTTON UP (input)
    init_gpio(PORT_A, DOWN_BUTTON, DIR_INPUT, PULLUP_ENABLED);

    // GPIO A5 is LED (output)
    init_gpio(PORT_A, BLUE_LED, DIR_OUTPUT, PULLUP_NOT_APPLICABLE);
    
    // GPIO A4 is input (USB Detect)
    init_gpio(PORT_A, USB_DETECT, DIR_INPUT, PULLUP_DISABLED);

    return err;
}

esp_err_t init_gpio(enum gpio_bank bank, const uint8_t gpio_number, enum io_direction dir, enum pull_up_state pullup_en)
{
    uint8_t recv_buffer = 0x00; // variable to hold register values
    esp_err_t err = ESP_OK;

    ESP_LOGI(TAG, "Initializing GPIO. Bank = %d, IO NUM = %d, DIREC = %d, PULLUP EN? %d", bank, gpio_number, dir, pullup_en);

    /////////////////////// Error checking ///////////////////////////

    if (gpio_number > 7)
    {
        ESP_LOGE(TAG, "GPIO number is invalid = %d", gpio_number);
        return ESP_ERR_INVALID_ARG;
    }

    //////////////////// Set up GPIO direction //////////////////////

    ESP_LOGI(TAG, "Setting up direction");
    // Read register (if bank is B, the register will be +1 of bank A)
    err = i2c_read_slave_register(IODIRA + (int)bank, &recv_buffer);
    if (err) return err;
  
    // Modify this bit only
    if (dir == DIR_OUTPUT)
    {
        // clear bit
        recv_buffer &= ~(1 << gpio_number);
    }
    else
    {
        // set bit
        recv_buffer |= (1 << gpio_number);
    }

    // Write new register values
    err = i2c_write_slave_register(IODIRA + (int)bank, recv_buffer);
    if (err) return err;

    /////////////////// Set up GPIO pullup (if input) /////////////////////

    // Set up GPIO pull_up if it is an input
    if (dir == DIR_INPUT)
    {
        ESP_LOGI(TAG, "Setting up pullup");
        // Read register and change only the bit we are interested in
        err = i2c_read_slave_register(GPPUA + (int)bank, &recv_buffer);
        if (err) return err;

        if (pullup_en == PULLUP_ENABLED)
        {
            recv_buffer |= (1 << gpio_number);  // high if pullup en
        }
        else
        {
            recv_buffer &= ~(1 << gpio_number);  // low if pullup disabled
        }

        err = i2c_write_slave_register(GPPUA + (int)bank, recv_buffer);
        if (err) return err;
    }
    else
    {
        ESP_LOGI(TAG, "Skipping pullup configuration as pin is input");
    }

    ESP_LOGI(TAG, "GPIO initialization complete!");

    return err;
}

// Write to a gpio pin on bank A or B. 0 will write 0 to pin. Any other number will write 1.
esp_err_t mcp23017_write_gpio(enum gpio_bank bank, uint8_t gpio_number, uint8_t value)
{
    uint8_t reading = 0x00;
    esp_err_t err = ESP_OK;
    uint8_t gpio_register = GPIOA + (int)bank; // Write to OLATA/B if do not want to reset the interrupt pin.

    // Get reading of register (if bank B, the addr is GPIOA + 1)
    err = i2c_read_slave_register(gpio_register, &reading);
    if (err) return err;

    // Create bitmask
    if (value > 0)
    {
        reading |= (1 << gpio_number);  // set bit for high
    }
    else
    {
        reading &= ~(1 << gpio_number);  // clear bit for low
    }

    // Write to register
    err = i2c_write_slave_register(gpio_register, reading);
    
    ESP_LOGI(TAG, "GPIO Write Complete!");

    return err;
}

// Reads gpio of one of the banks. Returns register value for the bank. Use READ_BIT(,) macro to read value of bit.
esp_err_t mcp23017_read_gpio_bank(enum gpio_bank bank, uint8_t* ret)
{
    esp_err_t err = ESP_OK;
    uint8_t gpio_address = GPIOA + (int)bank;

    // Get reading of register
    err = i2c_read_slave_register(gpio_address, ret);
    return err;
}

/*
 * Function: mcp23017_read_gpio
 *
 * Params: enum gpio_bank bank GPIO bank A or B to read
 * 
 * Return: bool Returns true for high, false for low for that gpio pin.
 * 
 * */
bool mcp23017_read_gpio(enum gpio_bank bank, uint8_t gpio_number)
{
    // Store reading here
    uint8_t reg = 0x00;

    // Read the bank
    mcp23017_read_gpio_bank(bank, &reg);

    // Get this gpio number value
    bool result = READ_BIT(reg, gpio_number);

    // Log for debugging
    ESP_LOGI(TAG, "GPIO %d = %x", gpio_number, result);
    
    return result;
}

esp_err_t disable_interrupt(enum gpio_bank bank, uint8_t gpio_number)
{
    ESP_LOGI(TAG, "Disabling interrupt on Bank %d, GPIO number %d", bank, gpio_number);

    esp_err_t err = ESP_OK;
    uint8_t recvbuffer = 0x00;

    // Get int enable register
    err = i2c_read_slave_register(GPINTENA + (int)bank, &recvbuffer);
    if (err) return err;

    recvbuffer &= ~ (1 << gpio_number);  // turn off interrupt

    // Write to register to turn it off
    err = i2c_write_slave_register(GPINTENA + (int)bank, recvbuffer);

    ESP_LOGI(TAG, "Interrupt disabled for bank %d gpio %d!", bank, gpio_number);

    return err;
}

/* Configures interrupt on mcp23017. Auto configures interrupt pin as active high.
 *   // GPTINTEN - 1 means interrupt enabled
 *   // DEFVAL - The default value of pin. If opposite will trigger interrupt
 *   // INTCON - 1 means look at defval, otherwise just trigger if pin state changes (any).
 *   // IOCON.ODR = open-drain interrupt pin. if set high, INTPOL is ignored.
 *   // INTPOL - polarity of interrupt pin. 1 is active high, 0 active low.
 *   // INTCAP holds value of gpio at the time interrupt occured
 *   // INTF tells us which GPIO triggered the interrupt
 * */
esp_err_t configure_interrupt(enum gpio_bank bank, uint8_t gpio_number, enum interrupt_trigger int_trigger)
{
    ESP_LOGI(TAG, "Configuring GPIO bank %d GPIO number %d with interrupt %d", bank, gpio_number, int_trigger);

    esp_err_t err = ESP_OK;
    uint8_t recvbuffer = 0x00;
    uint8_t intcon = 0x00;
    uint8_t defval = 0x00;

    // Check if pin is input
    err = i2c_read_slave_register(IODIRA + (int)bank, &recvbuffer);
    if (err) return err;

    if ( ((recvbuffer > gpio_number) & 1) == IO_EXPANDER_OUTPUT)
    {
        ESP_LOGE(TAG, "Cannot set interrupt on an output pin (pin %d).", gpio_number);
        return ESP_ERR_INVALID_ARG;
    }

    err = i2c_read_slave_register(GPINTENA + (int)bank, &recvbuffer);
    if (err) return err;

    err = i2c_read_slave_register(DEFVALA + (int)bank, &defval);
    if (err) return err;

    err = i2c_read_slave_register(INTCONA + (int)bank, &intcon);
    if (err) return err;

    // Enable interrupt
    recvbuffer |= (1 << gpio_number);

    // Configure interrupt comparison
    switch(int_trigger)
    {
        case MCP_RISING:
        {
            intcon |= (1 << gpio_number); // set incon bit so int trigger based on defval
            defval &= ~(1 << gpio_number); // clear defval bit. so default value is 0, and will trigger at logic 1.
        }break;
        
        case MCP_FALLING:
        {
            intcon |= (1 << gpio_number); // set incon bit so int trigger based on defval
            defval &= ~(1 << gpio_number); // set defval bit. so default value is 1, and will trigger at logic 0.
        }break;

        case MCP_ANY:
        {
            intcon &= ~(1 << gpio_number); // clear incon bit so int trigger on any pin
        }break;
        default:
        {
            ESP_LOGE(TAG, "Received a bad interrupt config %d", int_trigger);
            return ESP_ERR_INVALID_ARG;
        }break;
    }

    // Write to defval
    err = i2c_write_slave_register(DEFVALA + (int)bank, defval);
    if (err) return err;

    // Write to intcon
    err = i2c_write_slave_register(INTCONA + (int)bank, intcon);
    if (err) return err;

    // Write to GPINTEN
    err = i2c_write_slave_register(GPINTENA + (int)bank, recvbuffer);
    if (err) return err;

    // Set interrupt polarity to active high
    err = i2c_read_slave_register(IOCONA + (int)bank, &recvbuffer);
    if (err) return err;

    err = i2c_write_slave_register(IOCONA + (int)bank, recvbuffer |= IOCON_INTPOL);

    ESP_LOGI(TAG, "Interrupt configured for bank %d gpio %d!", bank, gpio_number);

    return err;
}


void app_main(void) // TODO: Interrupts + header file
{
    // Vars
    i2c_config_t i2cconfig;

    // 1. Configuration - set the init params, master/slave GPIO pins for SDA
    // SCL, CLK speed etc

    i2cconfig.mode = I2C_MODE_MASTER;
    i2cconfig.sda_io_num = SDA;
    i2cconfig.scl_io_num = SCL;
    i2cconfig.sda_pullup_en = GPIO_PULLUP_DISABLE;
    i2cconfig.scl_pullup_en = GPIO_PULLUP_DISABLE;
    i2cconfig.master.clk_speed = I2C_MAX_CLOCK_SPEED;
    i2cconfig.clk_flags = 0;

    ESP_ERROR_CHECK(i2c_param_config(I2C_PORT, &i2cconfig));

    // 2. Install Driver- activate driver on one of two I2C controllers as mtr
    // or slave

    ESP_ERROR_CHECK(i2c_driver_install(I2C_PORT, i2cconfig.mode, 0, 0, 0));
    
    ESP_LOGI(TAG, "I2C initialized successfully.");

    init_mcp23017();

    ESP_LOGI(TAG, "MCP initialized successfully.");

    const uint16_t delay_ms = 2000;
    uint8_t data = 0x00;

    while(1)
    {

        // Turn on LED
        ESP_LOGI(TAG, "Turning on blue LED %d seconds...", delay_ms/1000);
        vTaskDelay(pdMS_TO_TICKS(delay_ms));
        mcp23017_write_gpio(PORT_A, BLUE_LED, 1);

        // Turning off blue LED
        ESP_LOGI(TAG, "Turning off blue LED %d seconds...", delay_ms/1000);
        vTaskDelay(pdMS_TO_TICKS(delay_ms));
        mcp23017_write_gpio(PORT_A, BLUE_LED, 0);

        // Read GPIO bank
        // ESP_LOGI(TAG, "Will read gpio bank A %d seconds...", delay_ms/1000);
        // vTaskDelay(pdMS_TO_TICKS(delay_ms)); 
        // mcp23017_read_gpio_bank(PORT_A, &data);

        // ESP_LOGI(TAG, "OK = %d |  DOWN = %d| USB = %d", 
        //     READ_BIT(data, OK_BUTTON),
        //     READ_BIT(data, DOWN_BUTTON),
        //     READ_BIT(data, USB_DETECT));
        


    }

    // 7. Delete driver to release resources used by i2c drier.
    i2c_driver_delete(I2C_PORT);
}

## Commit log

2021-04-24 add project plan template
    [Project_planning.xlsx]
2021-04-24 finish project planning, add block diagram, add readme, gitignore
    [Project_planning.xlsx]
2021-04-24 update folders
    [Project_planning.xlsx]
2021-04-24 set up esp idf, vscode, and the start program.
    [Project_planning.xlsx]
2021-05-08 start schematic design. add use scenario. update notes.
    [ESP32 Pin Allocation.xlsx, Project_planning.xlsx, schem_1.kicad_pcb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]
2021-05-16 update gitignore to ignore kicad files
2021-05-16 add 128x32 oled to schem. add new symbols to library. add backup power (supercap) circuit. update plan. add esp32 pinouts
    [ESP32 Pin Allocation.xlsx, I2C_OLED.sch, Project_planning.xlsx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]
2021-05-22 update schematic: add io expander with peripherals, update power circuitry- change some components. update project plan. update footprints
    [ESP32 Pin Allocation.xlsx, I2C_OLED.sch, Project_planning.xlsx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]
2021-05-23 Replace ESP32 Wroom module with WRover and remove the external PSRAM (as Wrover has one built in). Create symbol and footprint for Wrover. Update footprints for resistors and buttons. Update USB foot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
    [ESP32-S2-WROVER.step, I2C_OLED.sch, Project_planning.xlsx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]
2021-05-29 change supercap for one with lower esr and shorter. create footprint and 3d model for new cap. remove power switch entirely.
    [io_expander.sch, power.sch, schem_1.kicad_pcb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]
2021-05-30 update footprint for OLED display (no longer using ffc connector)
    [I2C_OLED.sch, schem_1.kicad_pcb]
2021-06-05 update footprints for 24way connector, 3D models. add new connector to connect the two PCB's
    [528922433.stp, CUI_DEVICES_UJ2-MBH-1-SMT.step, DGH105Q5R5-Body.step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]
2021-06-12 add correct 3d model for esp32 wrover e. initial placement of components done for both boards. need to start routing
    [ESP32-WROVER-I--3DModel-STEP-56544.STEP, Project_planning.xlsx, power.sch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]
2021-06-13 lay tracks and zones for front pcb.
    [schem_1.kicad_pcb]
2021-06-19 finish first round tracks and filled zones for front PCB. Do silk screen
    [schem_1.kicad_pcb, schem_1.sch]
2021-06-20 finish laying tracks and the layers on back pcb. modify some footprints as their courtyards were giving errors. 0 drc errors
    [schem_1.kicad_pcb]
2021-06-20 joined the PCBs together with mouse bites
    [schem_1.kicad_pcb]
2021-06-20 'productionize' the hardware. update project plan spreadsheet'
    [Project_planning.xlsx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]
2021-08-01 update to latest gerbers, update project plan
    [I2C_OLED.sch, Project_planning.xlsx, io_expander.sch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]
2021-08-01 update README, add image folder
    [schem_1.kicad_pcb]
2021-08-22 add new update to project log. all 3 24-way fpc's connected. will continue validating hardware and make relevant changes for spin 2
    [Project_planning.xlsx]
2021-08-29 move old production stuff to new folder. start pcb spin 2: add test points (smd and pads). add third diode as currently disconnected USB can not be detected. increase LED resistor values are too brig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
    [Project_planning.xlsx, io_expander.sch, power.sch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]
2021-08-30 make board on breadboard for easier debugging and fixing. will start writing f/w on this board
    [Project_planning.xlsx, power.sch, schem_1.kicad_pcb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]
2021-09-11 start writing mcp2017 driver. testing register writes/reads in this push
2021-09-11 test led blinking through io expander (works)
2021-09-12 add interrupt init functions
